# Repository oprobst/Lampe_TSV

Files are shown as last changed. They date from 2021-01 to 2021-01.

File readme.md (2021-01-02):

# TSV LED Sign

While cleaning up our workshop in our [TSV Malsch divers club](https://tsv-malsch.de), we found an old sign. It was equiped with E27 bulbs and some stroboscope flashes.
We decided activate it again and update it with RGB LED stripes. 
Since there were still some parts left in my electronic magazine cabinet, i decided to implement an LED controller at a reasonable price.

We extended the sign by a separate RGB LED Stripe array for the diver, and stripes for letters 'T', 'S', 'V'.
The circuit includes a button for selecting mode and some optional, internal status LEDs.

A button triggers an interrupt for an options menu. With this, the user can distinguish between 4 different modes.

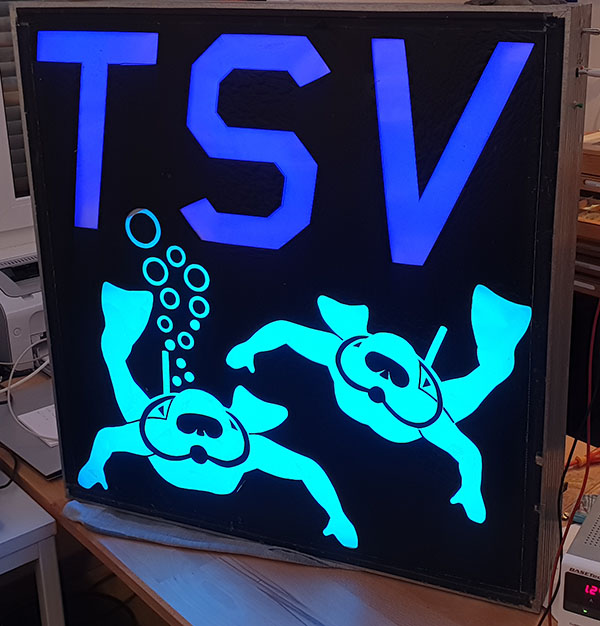
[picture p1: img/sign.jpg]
photo of the sign with led


The code could be more elegant, but it works. :)

## Modes

To change the mode, push the button on the left to switch through the differen options (visualized by a highlighted letter on the sign). 

First default mode is for the sign placed on the wall in the clubs workshop. Blue text and a slightly changing diver from green to blue and back.
Second and third changes the divers color constantly and also switching the letters color. Difference is the speed: While mode 2 is very slow (eg. for using it when selling things on a festival), mode 3 is fast and can be used on parties. Mode 4 is the disco mode, the whole sign flashes fast.

## Implementation

The controller is an Atmel ATMega 328P. It controls the major RGB light by 3 PWM pins. These 3 pins are connected to N-Channel mosfets (IRLZ 34N in this case). So it's possible to switch up to 68W per Channel. Unfortunatelly, the layout is not optimal, there is no place for heat sinks and the mosfest are close together. Very likely, this maximum is far out. But since the sign is currenly only using less than 4W per channel, this is not a problem..

To save costs, all other channels running a NPN transistor (BC550). This limits the maximum current to 100mA (= 1.2W on 12V).

## Wiring

Numbered from left to right when looking at the circuit from the top, black terminal bottom right. The black terminal is for connecting to 12V. The connector closest to the corner is GND.

Green Terminal (3.5mm)
| Pin | Purpose |
| ---: | --- |
|  1 | +12V out |
|  2 | High current RED channel |
|  3 | High current GREEN channel |
|  4 | High current BLUE channel |
|  5 | +12V out |
|  6 | Low current RED channel 1 |
|  7 | Low current GREEN channel 1 |
|  8 | Low current BLUE channel 1 |
|  9 | +12V out |
| 10 | Low current RED channel 2 |
| 11 | Low current GREEN channel 2 |
| 12 | Low current BLUE channel 2 |
| 13 | +12V out |
| 14 | Low current RED channel 3 |
| 15 | Low current GREEN channel 3 |
| 16 | Low current BLUE channel 3 |
| 17 | Multi purpose output 5V with 220 Ohm resistor, eg. for LED |
| 18 | Multi purpose output 5V with 220 Ohm resistor, eg. for LED |
| 19 | Multi purpose output 5V with 220 Ohm resistor, eg. for LED (used for button in V1.0) |
| 20 | Multi purpose output 5V with 220 Ohm resistor, eg. for LED (not connected in V1.0) |
| 21 | Multi purpose output 5V with 220 Ohm resistor, eg. for LED (not connected in V1.0) |
| 22 | +5V out |
| 23 | GND |
| 24 | Input pin for button. Push-up active, switch against GND to trigger |

## Pin out

### Diver LED:
* PD6 red	
* PD5 green
* PD3 blue

### Letter T
* PD4 red
*	PB0 green
*	PD7 blue

### Letter S
* PD0 red
*	PD1 green
*	PD2 blue

### Letter V
* PC3 red
*	PC5 green
*	PC4 blue

Input button: V1.0: PC0 V1.1: PB6  (Since there was a defect on the board 1.0, I used PC0 instead)
Status LED: PC1, PC2 (additional PC0, PB1, PB2 not connected so far)

## Circuit
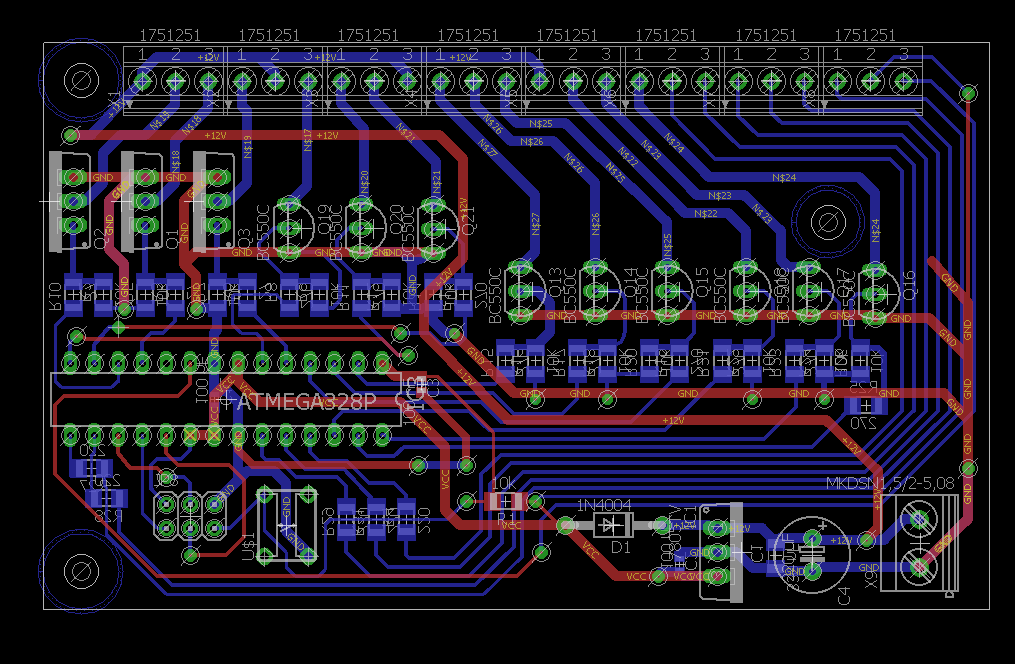
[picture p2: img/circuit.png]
Screenshot of circuit


## Schematics
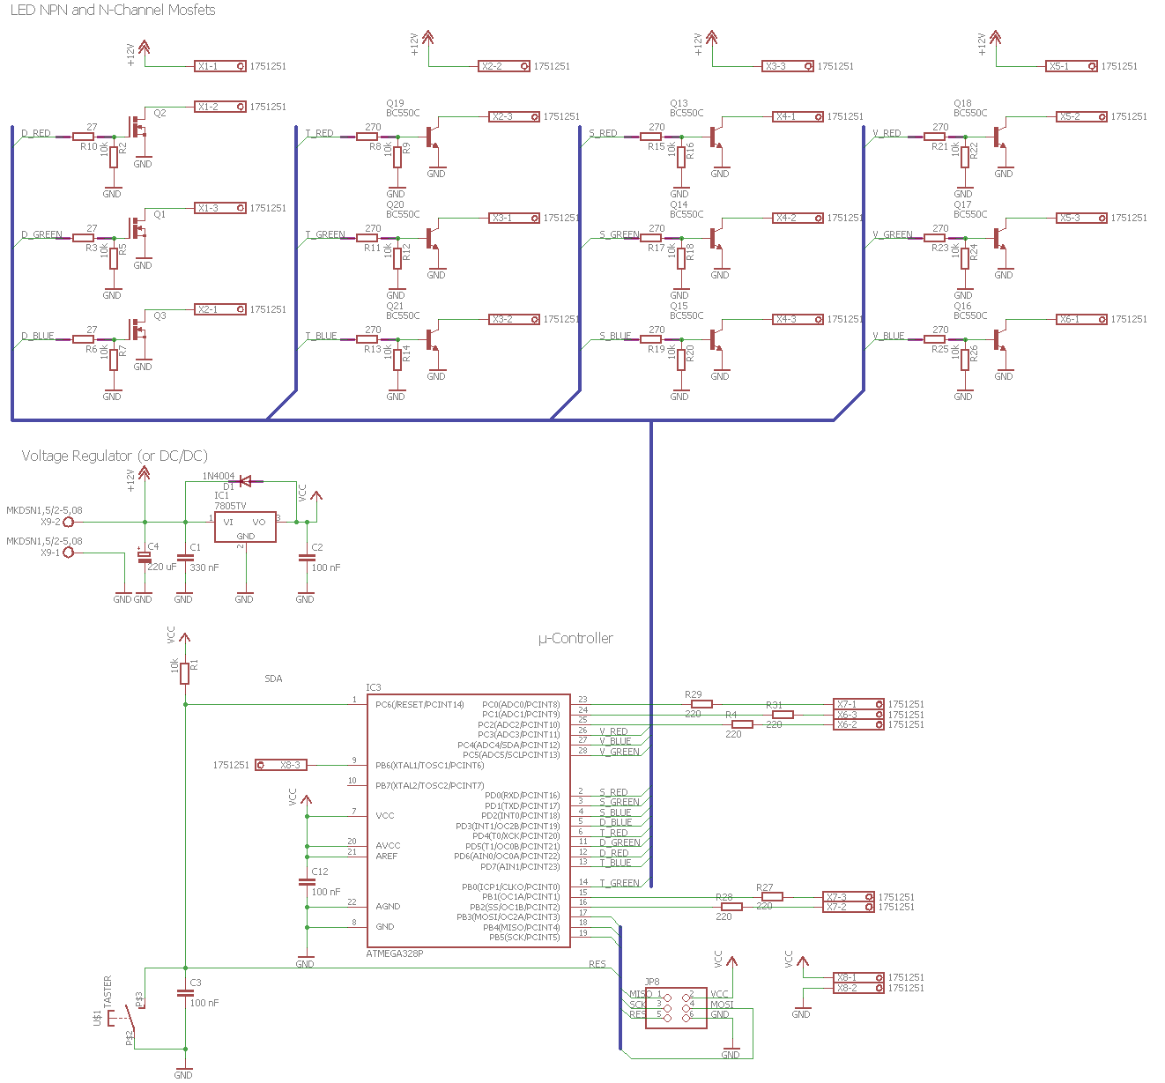
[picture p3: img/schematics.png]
Screenshot of schematics


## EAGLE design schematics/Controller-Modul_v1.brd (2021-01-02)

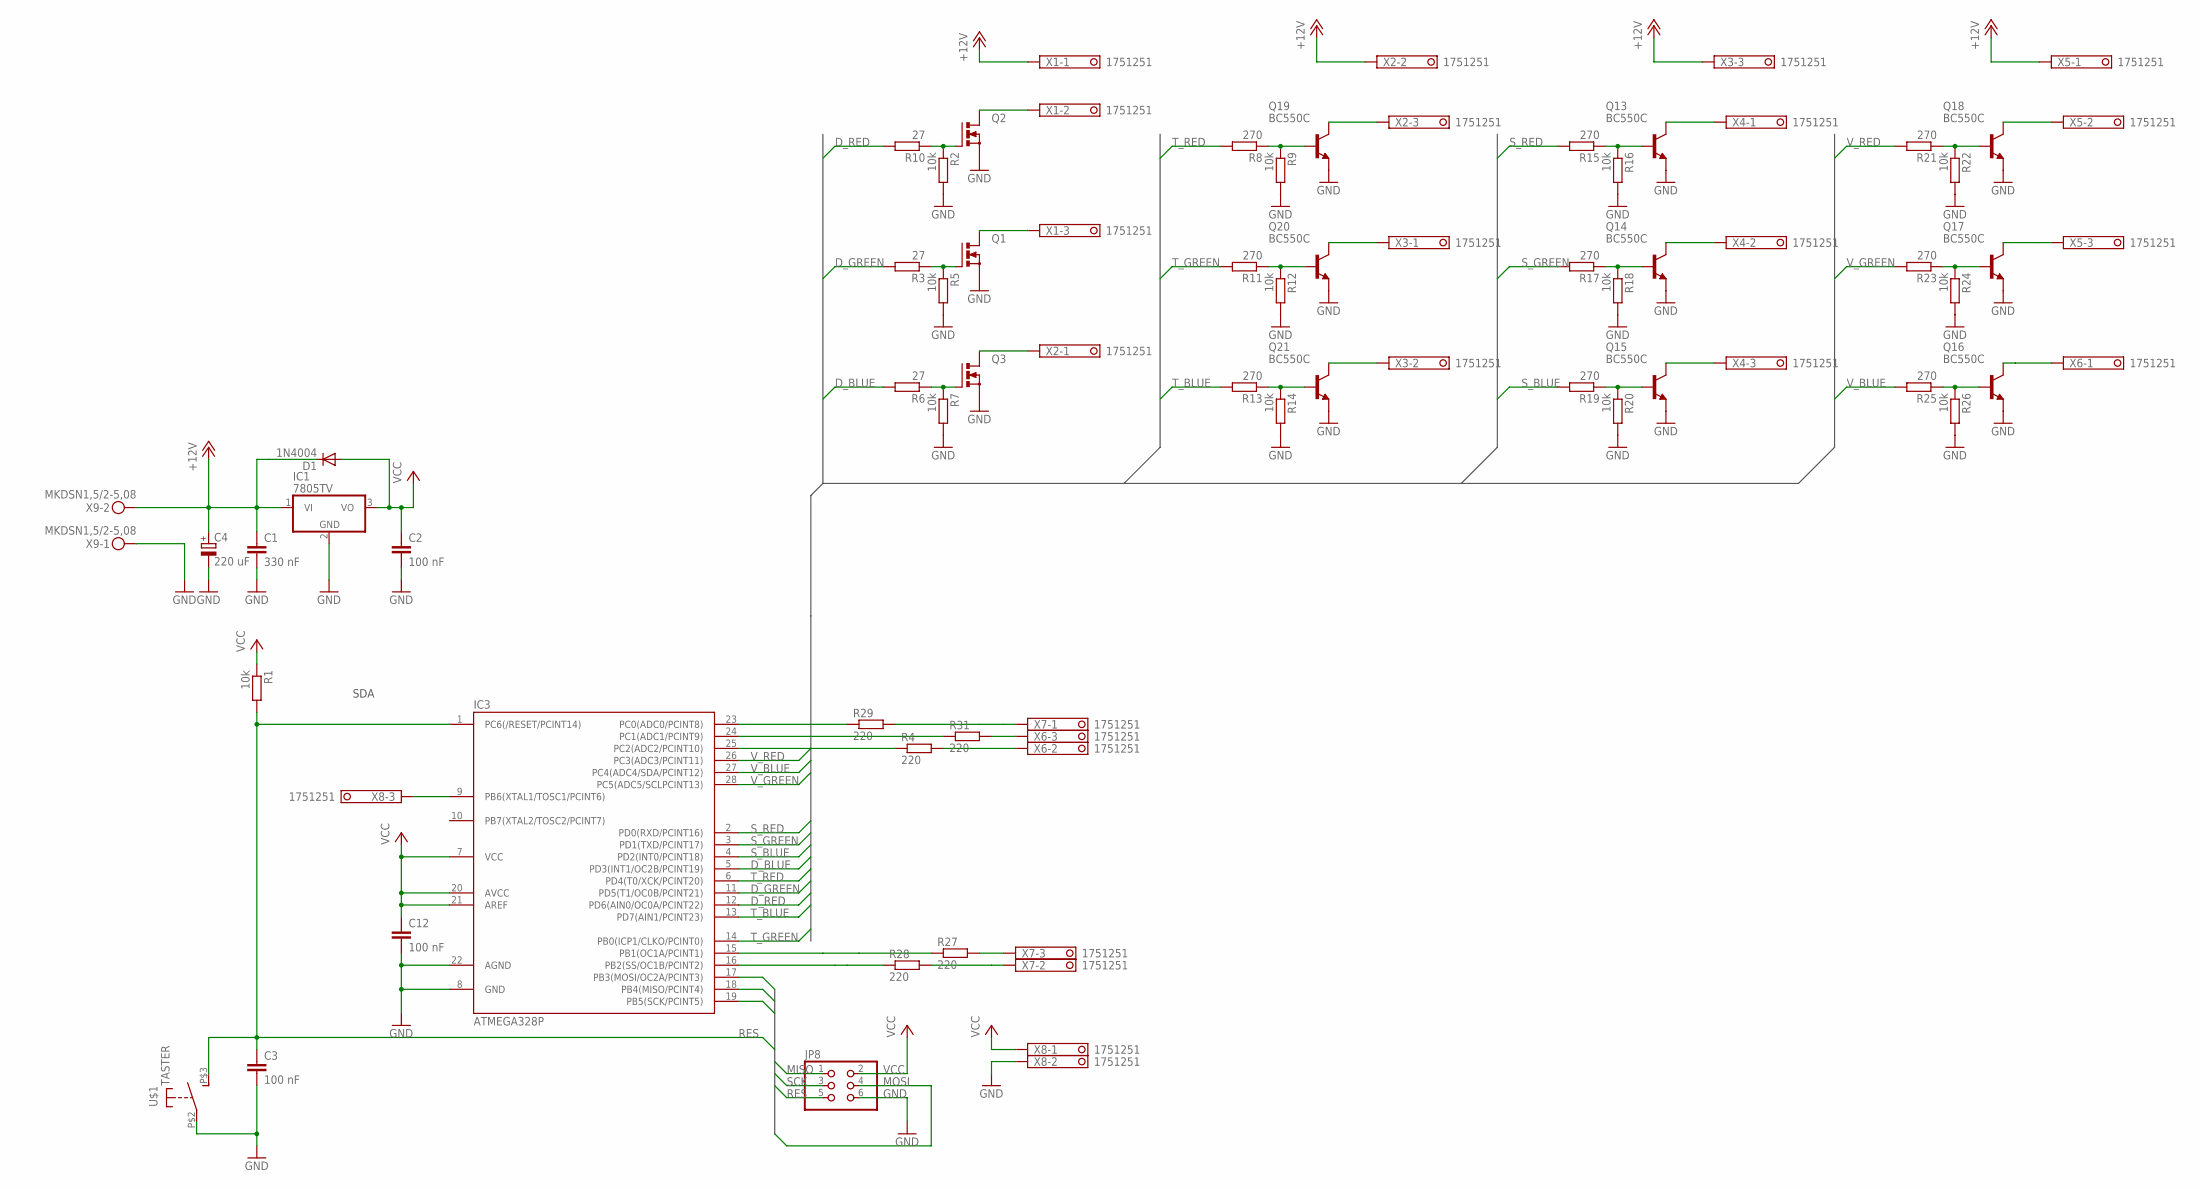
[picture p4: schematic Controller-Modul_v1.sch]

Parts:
C1: 330 nF; C1206
C2, C3, C12: 100 nF; C0603
C4: 220 uF; E3,5-8
D1: 1N4004; DO41-10
IC1: 7805TV; TO220V
IC3: ATMEGA328P; DIL28-3
JP8: PINHD-2X3; 2X03
Q1, Q2, Q3: PMOSFET_NTO220BV; TO220BV
Q13, Q14, Q15, Q16, Q17, Q18, Q19, Q20, Q21: BC550C; TO92-EBC
R1, R2, R5, R7, R9, R12, R14, R16, R18, R20, R22, R24, R26: 10k; R1206
R3, R6, R10: 27; R1206
R4, R27, R28, R29, R31: 220; R1206
R8, R11, R13, R15, R17, R19, R21, R23, R25: 270; R1206
U$1: TASTER; NAMAE-JTP-1130
X1, X2, X3, X4, X5, X6, X7, X8: 1751251
X9: MKDSN1,5/2-5,08

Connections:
+12V: C1.1, C4.+, D1.C, IC1.1 (VI), X1.1, X2.2, X3.3, X5.1, X9.2
D_BLUE: IC3.5 (PD3(INT1/OC2B/PCINT19)), R6.2
D_GREEN: IC3.11 (PD5(T1/OC0B/PCINT21)), R3.2
D_RED: IC3.12 (PD6(AIN0/OC0A/PCINT22)), R10.2
GND: C1.2, C2.2, C3.2, C4.-, C12.2, IC1.2 (GND), IC3.8 (GND), IC3.22 (AGND), JP8.6, Q1.S, Q2.S, Q3.S, Q13.E, Q14.E, Q15.E, Q16.E, Q17.E, Q18.E, Q19.E, Q20.E, Q21.E, R2.2, R5.2, R7.2, R9.2, R12.2, R14.2, R16.2, R18.2, R20.2, R22.2, R24.2, R26.2, U$1.P$2, X8.2, X9.1
MISO: IC3.18 (PB4(MISO/PCINT4)), JP8.1
MOSI: IC3.17 (PB3(MOSI/OC2A/PCINT3)), JP8.4
unnamed: Q1.G, R3.1, R5.1
unnamed: Q3.G, R6.1, R7.1
unnamed: IC3.24 (PC1(ADC1/PCINT9)), R31.1
unnamed: Q19.B, R8.1, R9.1
unnamed: Q20.B, R11.1, R12.1
unnamed: Q2.G, R2.1, R10.1
unnamed: Q21.B, R13.1, R14.1
unnamed: Q13.B, R15.1, R16.1
unnamed: Q14.B, R17.1, R18.1
unnamed: Q15.B, R19.1, R20.1
unnamed: Q18.B, R21.1, R22.1
unnamed: Q17.B, R23.1, R24.1
unnamed: Q16.B, R25.1, R26.1
unnamed: Q2.D, X1.2
unnamed: Q19.C, X2.3
unnamed: Q1.D, X1.3
unnamed: Q3.D, X2.1
unnamed: Q20.C, X3.1
unnamed: Q21.C, X3.2
unnamed: Q18.C, X5.2
unnamed: Q17.C, X5.3
unnamed: Q16.C, X6.1
unnamed: Q15.C, X4.3
unnamed: Q14.C, X4.2
unnamed: Q13.C, X4.1
unnamed: IC3.25 (PC2(ADC2/PCINT10)), R4.1
unnamed: IC3.23 (PC0(ADC0/PCINT8)), R29.1
unnamed: IC3.15 (PB1(OC1A/PCINT1)), R27.1
unnamed: IC3.16 (PB2(SS/OC1B/PCINT2)), R28.1
unnamed: R31.2, X6.3
unnamed: R4.2, X6.2
unnamed: R27.2, X7.3
unnamed: R29.2, X7.1
unnamed: R28.2, X7.2
unnamed: IC3.9 (PB6(XTAL1/TOSC1/PCINT6)), X8.3
RES: C3.1, IC3.1 (PC6(/RESET/PCINT14)), JP8.5, R1.2, U$1.P$3 (S)
SCK: IC3.19 (PB5(SCK/PCINT5)), JP8.3
S_BLUE: IC3.4 (PD2(INT0/PCINT18)), R19.2
S_GREEN: IC3.3 (PD1(TXD/PCINT17)), R17.2
S_RED: IC3.2 (PD0(RXD/PCINT16)), R15.2
T_BLUE: IC3.13 (PD7(AIN1/PCINT23)), R13.2
T_GREEN: IC3.14 (PB0(ICP1/CLKO/PCINT0)), R11.2
T_RED: IC3.6 (PD4(T0/XCK/PCINT20)), R8.2
VCC: C2.1, C12.1, D1.A, IC1.3 (VO), IC3.7 (VCC), IC3.20 (AVCC), IC3.21 (AREF), JP8.2, R1.1, X8.1
V_BLUE: IC3.27 (PC4(ADC4/SDA/PCINT12)), R25.2
V_GREEN: IC3.28 (PC5(ADC5/SCLPCINT13)), R23.2
V_RED: IC3.26 (PC3(ADC3/PCINT11)), R21.2

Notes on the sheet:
SDA

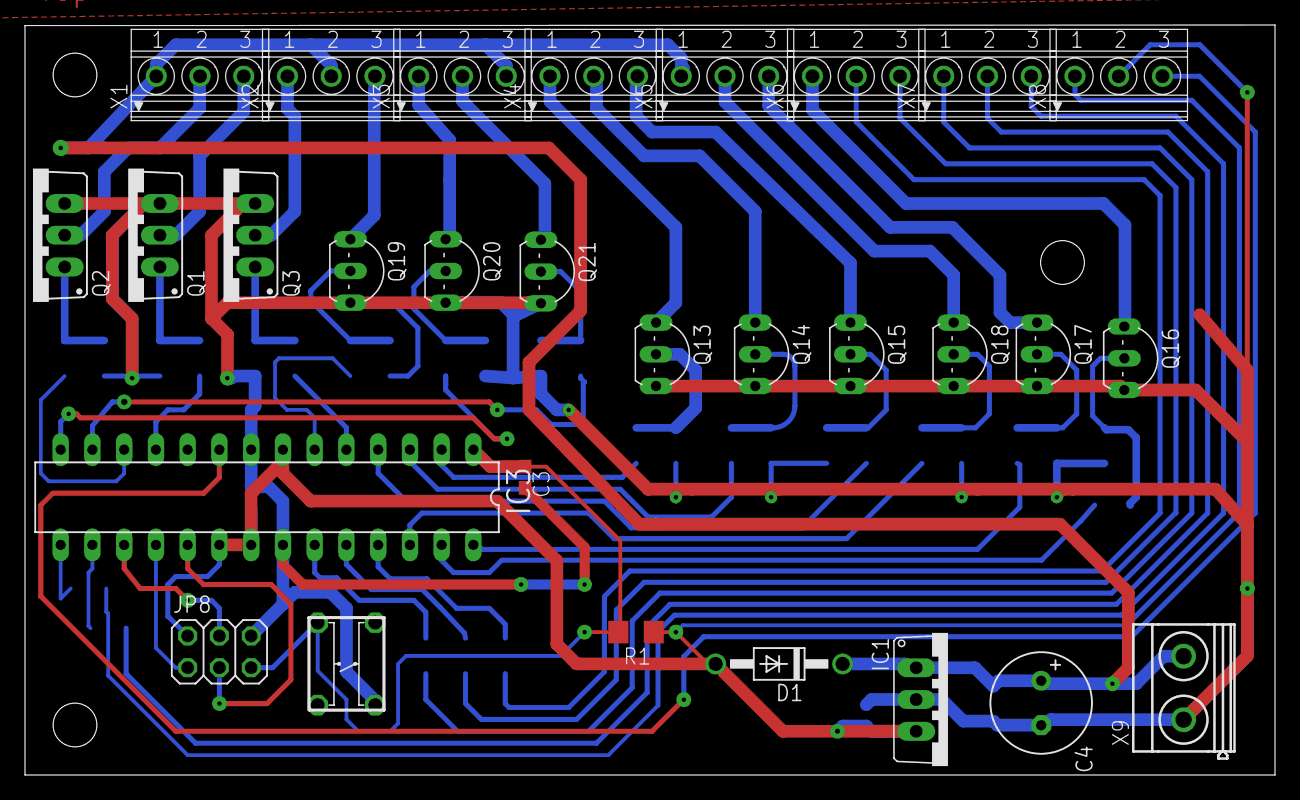
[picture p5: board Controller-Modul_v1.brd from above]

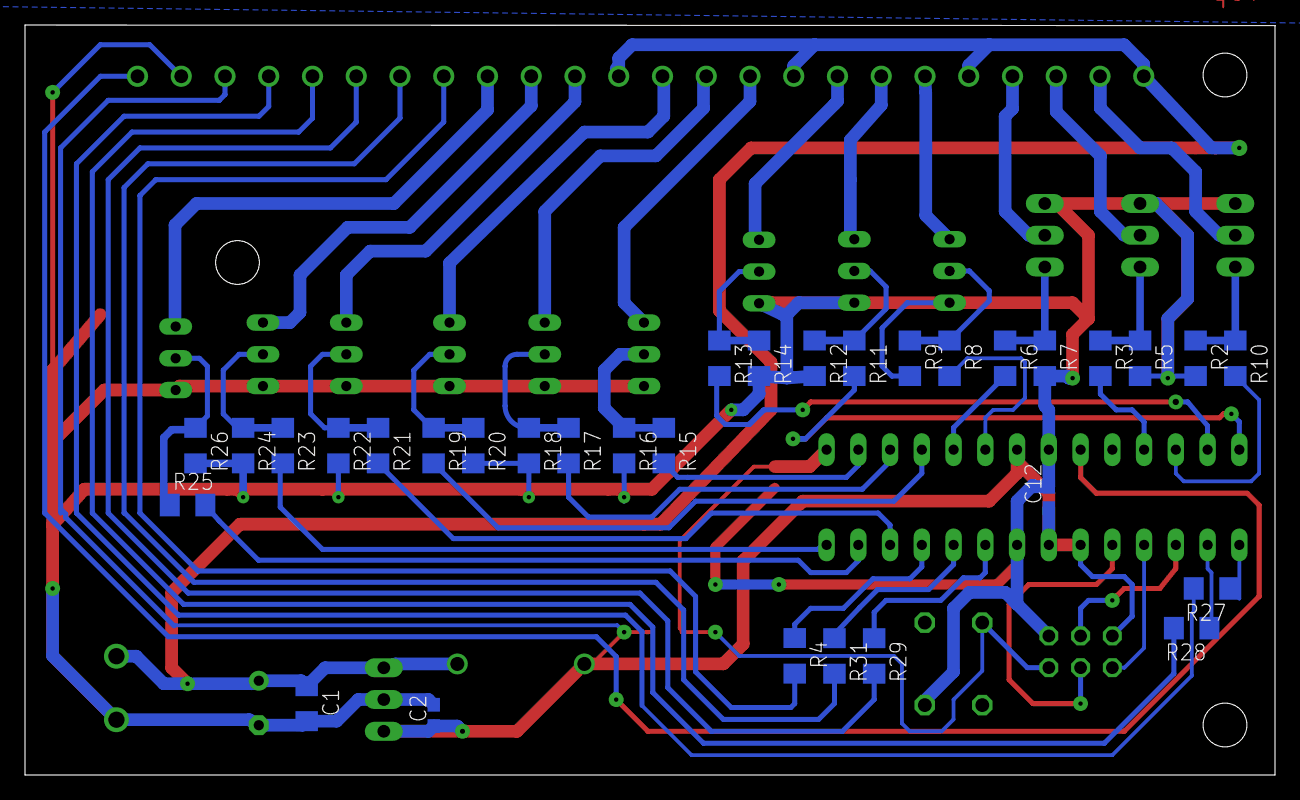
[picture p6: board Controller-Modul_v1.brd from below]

Board: 2 copper layers, 100.0 x 60.0 mm, 61 parts (32 on the bottom side), 54 nets.

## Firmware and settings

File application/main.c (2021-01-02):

#define F_CPU 8000000

#include <avr/io.h>
#include <util/delay.h>
#include <stdint.h>
#include <stdlib.h>
#include <avr/interrupt.h>

#define OFF 0
#define RED 1
#define GREEN 2
#define BLUE 3
#define PURPLE 4
#define CYAN 5
#define YELLOW 6
#define WHITE 7

#define FALSE 0
#define TRUE 1

#define SKIP_INTRO 0

static  uint8_t optionSelected = 1;
static volatile uint8_t gotoMenu = FALSE;

/* 
TSV LED Sign

Contains RGB LED Stripe array for diver, and stripes for  for letters 'T', 'S', 'V'.
Includes a button for selecting mode and some optional status LEDs.

Circuit Layout

Diver LED:		Letter T	Letter S	Letter V
PD6 red			PD4 red		PD0 red		PC3 red
PD5 green		PD7 blue	PD1 green	PC5 green
PD3 blue		PB0 green	PD2 blue	PC4 blue

Input button: PB6
Status LED: PC1, PC2 (additional PC0, PB1, PB2 not connected so far)

*/


void setup() {
	//init output pins
	DDRB |= (1<<PB0) | (1<<PB1) | (1<<PB2);
	DDRC |= (1<<PC1) | (1<<PC2) | (1<<PC3) | (1<<PC4) | (1<<PC5);
	DDRD |= (1<<PD0) | (1<<PD1) | (1<<PD2) | (1<<PD3) | (1<<PD4) | (1<<PD5) | (1<<PD6) | (1<<PD7);
	
	// set pin for button
	PORTC = (1<<PC0);
	DDRC &= ~(1 << PINC0);
	
	//init PWMs:
	//OC2B (PD3) - Diver blue
	//OC0B (PD5) - Diver green
	//OC0A (PD6) - Diver red
	 
	TCCR2A |= (1 << COM2B1);
	TCCR2A |= (1 << WGM21) | (1 << WGM20);
	TCCR0B  |= (1 << WGM01) | (1 << WGM00);
	TCCR0A |= (1<<COM0B1);
	TCCR0A |= (1 << COM0A1);
	TCCR0A |= (1 << WGM01) | (1 << WGM00);
	TCCR0B |= (1 << CS01);
	TCCR2B |= (1 << CS01);
	
	//pin change interrupt for PCINT 8 (=PC0 --> Button)
	PCICR |= (1 << PCIE1);
	PCMSK1 |= (1 << PCINT8);
	
	sei();
	
}

 
/*
 * Convenience method so set diver color.
 */ 
void colorDiver (uint8_t red, uint8_t green, uint8_t blue){
	OCR0A = red;
	OCR0B = green;
	OCR2B = blue;
}

/* 
 *Convenience method for letter. Use defined colors, like colorT(BLUE); 
 */
void colorT (uint8_t color){
	switch (color){
		case OFF:
			PORTB &= ~(1 << PB0);
			PORTD &= ~(1 << PD7);
			PORTD &= ~(1 << PD4);
			break;
		case BLUE:
			PORTB &= ~(1 << PB0);
			PORTD |=  (1 << PD7);
			PORTD &= ~(1 << PD4);
			break;
		case GREEN:
			PORTB |=  (1 << PB0);
			PORTD &= ~(1 << PD7);
			PORTD &= ~(1 << PD4);
			break;
		case RED:
			PORTB &= ~(1 << PB0);
			PORTD &= ~(1 << PD7);
			PORTD |=  (1 << PD4);
			break;
		case PURPLE:
			PORTB &= ~(1 << PB0);
			PORTD |=  (1 << PD7);
			PORTD |=  (1 << PD4);
			break;
		case YELLOW:
			PORTB |=  (1 << PB0);
			PORTD &= ~(1 << PD7);
			PORTD |=  (1 << PD4);
			break;
		case CYAN:
			PORTB |=  (1 << PB0);
			PORTD |=  (1 << PD7);
			PORTD &= ~ (1 << PD4);
			break;
		default: 
			PORTB |=  (1 << PB0);
			PORTD |=  (1 << PD7);
			PORTD |=  (1 << PD4);
			break;
	}
}

/* 
 *Convenience method for letter. Use defined colors, like colorS(BLUE); 
 */
void colorS (uint8_t color){
	switch (color){
		case OFF:
			PORTD &= ~(1 << PD0);
			PORTD &= ~(1 << PD1);
			PORTD &= ~(1 << PD2);
			break;
		case RED:
			PORTD |=  (1 << PD0);
			PORTD &= ~(1 << PD1);
			PORTD &= ~(1 << PD2);
			break;
		case GREEN:
			PORTD &= ~(1 << PD0);
			PORTD |=  (1 << PD1);
			PORTD &= ~(1 << PD2);
			break;
		case BLUE:
			PORTD &= ~(1 << PD0);
			PORTD &= ~(1 << PD1);
			PORTD |=  (1 << PD2);
			break;
		case PURPLE:
			PORTD |=  (1 << PD0);
			PORTD &= ~(1 << PD1);
			PORTD |=  (1 << PD2);
			break;
		case YELLOW:
			PORTD |=  (1 << PD0);
			PORTD |=  (1 << PD1);
			PORTD &= ~(1 << PD2);
			break;
		case CYAN:
			PORTD &= ~(1 << PD0);
			PORTD |=  (1 << PD1);
			PORTD |=  (1 << PD2);
			break;
		default: 
			PORTD |=  (1 << PD0);
			PORTD |=  (1 << PD1);
			PORTD |=  (1 << PD2);
			break;
	}
}


/* 
 *Convenience method for letter. Use defined colors, like colorV(BLUE); 
 */
void colorV (uint8_t color){
	switch (color){
		case OFF:
			PORTC &= ~(1 << PC4);
			PORTC &= ~(1 << PC5);
			PORTC &= ~(1 << PC3);
			break;
		case BLUE:
			 PORTC |=  (1 << PC4);
			 PORTC &= ~(1 << PC5);
			 PORTC &= ~(1 << PC3);
			 break;
		case GREEN:
			PORTC &= ~(1 << PC4);
			PORTC |=  (1 << PC5);
			PORTC &= ~(1 << PC3);
			break;
		case RED:
			PORTC &= ~(1 << PC4);
			PORTC &= ~(1 << PC5);
			PORTC |=  (1 << PC3);
			break;
		case PURPLE:
			PORTC |=  (1 << PC4);
			PORTC &= ~(1 << PC5);
			PORTC |=  (1 << PC3);
			break;
		case CYAN:
			PORTC |=  (1 << PC4);
			PORTC |=  (1 << PC5);
			PORTC &= ~(1 << PC3);
			break;
		case YELLOW:
			PORTC &= ~(1 << PC4);
			PORTC |=  (1 << PC5);
			PORTC |=  (1 << PC3);
			break;
		default: 
			PORTC |=  (1 << PC4);
			PORTC |=  (1 << PC5);
			PORTC |=  (1 << PC3);
			break;
	}
}

/*
 * Color for all letters
 */
void colorTSV (uint8_t t, uint8_t s, uint8_t v){
	colorT(t);
	colorS(s);
	colorV(v);
}
/*
 * Fancy start up animation
 */
void initSequence(){

    if (SKIP_INTRO) return;
	
	double speedLetter = 30; //ms
	double speedBlink = 350; //ms
	double fastBlink = 150; //ms


    uint8_t dRed = 0;
	uint8_t dGreen = 0;
	uint8_t dBlue = 0;

	colorDiver (0, 222, 1);
	colorTSV(CYAN, OFF, OFF);
	
	for (uint8_t i = 0; i < 20 ; i++){
	  dGreen += 1;
	  dRed += 1;
	  colorDiver (dRed, dGreen, dBlue);
	  _delay_ms(speedLetter);
	}		
	colorTSV(OFF, CYAN, OFF);
	
	for (uint8_t i = 0; i < 20 ; i++){
		dGreen += 1;
		dRed += 1;
		colorDiver (dRed, dGreen, dBlue);
		_delay_ms(speedLetter);
		if (gotoMenu) return;
	}
		
	colorTSV(OFF, OFF, CYAN);
	
	for (uint8_t i = 0; i < 40 ; i++){
		dBlue += 1;
		dRed -= 1;
		colorDiver (dRed, dGreen, dBlue);
		_delay_ms(speedLetter);
		if (gotoMenu) return;
	}
 
	
	colorTSV(CYAN, OFF, CYAN);
	
	for (uint8_t i = 0; i < 20 ; i++){		
		dGreen -= 1;
		colorDiver (dRed, dGreen, dBlue);
		_delay_ms(speedLetter);
		if (gotoMenu) return;
	}
	
	colorTSV(OFF, CYAN, CYAN);
	
	for (uint8_t i = 0; i < 20 ; i++){			
		dGreen -= 1;
		colorDiver (dRed, dGreen, dBlue);
		_delay_ms(speedLetter+speedLetter);
		if (gotoMenu) return;
	}
	
	
		
	colorTSV(CYAN, CYAN, CYAN);
	
	for (uint8_t i = 0; i < 20 ; i++){
		dRed += 1;
		colorDiver (dRed, dGreen, dBlue);
		_delay_ms(speedLetter);
		if (gotoMenu) return;
	}
		
	colorTSV(CYAN, CYAN, CYAN);
	_delay_ms(speedBlink);
	colorTSV(BLUE, BLUE, BLUE);
	_delay_ms(speedBlink);
	colorTSV(CYAN, CYAN, CYAN);
	_delay_ms(speedBlink);
	colorTSV(BLUE, BLUE, BLUE);	
	_delay_ms(speedBlink);
	for (uint8_t i = 0; i < 2; i++){
		colorTSV(RED, RED, RED);
		colorDiver (0, 255, 255);
		_delay_ms(fastBlink);		
		colorTSV(BLUE, BLUE, BLUE);
		_delay_ms(fastBlink);
		colorTSV(RED, RED, RED);
		colorDiver (dRed, dGreen, dBlue);
		_delay_ms(fastBlink);
		colorTSV(BLUE, BLUE, BLUE);
		
		_delay_ms(fastBlink);
	}
	
	for (uint8_t i = 0; i < 250 ; i++){			
		if (dRed >  5) dRed -= 1;
		if (dGreen < 250) dGreen += 1;
		if (dBlue < 250) dBlue += 1;
		colorDiver (dRed, dGreen, dBlue);
		_delay_ms(speedLetter+speedLetter);
		if (gotoMenu) return;
	}	
	
}

/*
 * this helper is used by mode2() and mode3()
void animationMode (double speed){
	uint8_t dRed = 0;
	uint8_t dGreen = 250;
	uint8_t dBlue = 250;			
	uint32_t wait = 0;
	while(!gotoMenu) {

		// fade green
		colorTSV(CYAN, GREEN, YELLOW);
		for (uint8_t i = 0; i < 250 ; i++){
			dBlue -= 1;
			colorDiver (dRed, dGreen, dBlue);
			while (wait++ < speed) _delay_ms(1);
			wait = 0;
			if (gotoMenu) return;
		}
		// fade yellow
		colorTSV(GREEN, YELLOW, PURPLE);
		for (uint8_t i = 0; i < 250 ; i++){
			dRed += 1;
			colorDiver (dRed, dGreen, dBlue);
			while (wait++ < speed) _delay_ms(1);
			wait = 0;
			if (gotoMenu) return;
		}		
		// fade purple
		colorTSV(YELLOW, PURPLE, BLUE);
		for (uint8_t i = 0; i < 250 ; i++){
			dBlue  += 1;
			dGreen -= 1;
			colorDiver (dRed, dGreen, dBlue);
			while (wait++ < speed) _delay_ms(1);
			wait = 0;
			if (gotoMenu) return;
		}
		// fade blue
		colorTSV(PURPLE, BLUE, CYAN);
		for (uint8_t i = 0; i < 250 ; i++){			
			dRed -= 1;
			colorDiver (dRed, dGreen, dBlue);
			while (wait++ < speed) _delay_ms(1);
			wait = 0;
			if (gotoMenu) return;
		}
		// fade cyan
		colorTSV(BLUE, CYAN, GREEN);
		for (uint8_t i = 0; i < 250 ; i++){
			dGreen  += 1;			
			colorDiver (dRed, dGreen, dBlue);
			while (wait++ < speed) _delay_ms(1);
			wait = 0;
			if (gotoMenu) return;
		}	
		
	}
}

/*
 * Default mode: from cyan to green and back within ca 1/2 hour. Text stays blue.
 */ 
void mode1 (){
	
	while(!gotoMenu) {
		double speed = 35;//ms
		uint8_t dRed = 5;
		uint8_t dGreen = 250;
		colorTSV(BLUE, BLUE, BLUE);
		 
		for (uint8_t i = 250; i > 0 ; i--){			
			colorDiver (dRed, dGreen, i);
			_delay_ms(speed);
			for (uint8_t j = 0; j < 100 ; j++){
				_delay_ms(speed);
				if (gotoMenu) return;
			}
		}
		for (uint8_t i = 0; i < 250 ; i++){		
			colorDiver (dRed, dGreen, i);
			for (uint8_t j = 0; j < 100 ; j++){
				_delay_ms(speed);
				if (gotoMenu) return;
			}
			
		}
	
	}		
}

/*
 * Mode 2: Colorful - changes colors slowly 
 */ 
void mode2 (){
	animationMode(100);
}

/*
 * Mode 3: Colorful - changes colors fast (eg. for party)
 */ 
void mode3 (){
	animationMode(10);
}


/*
 * Mode 4: Disco mode
 */ 
void mode4 (){
	
	uint8_t colorText = 1;
	while(optionSelected == 4) {
		if (++colorText > 8) colorText = 1;
		
		for (uint8_t i = 0; i < 5 ; i++){		
			colorDiver ( 255, 255,255);
			colorTSV (colorText, colorText, colorText);
			_delay_ms(30);
			colorDiver (0, 0, 0);
			colorTSV (0, 0, 0);
			_delay_ms(150);
			if (gotoMenu) return;
		}
	
	}		
}

/*
 * Change to user selected mode
 */
void changeMode (){
	gotoMenu = FALSE;
	switch (optionSelected){
		case 2:
		mode2();
		break;
		case 3:
		mode3();
		break;
		case 4:
		mode4();
		break;
		default:
		mode1();
		break;
	}
}
/*
 * Interrupt when button is pushed
 */
ISR(PCINT1_vect)
{
	gotoMenu = TRUE;
}

/*
 * Gives the user the opportunity to select the mode (workshop/party-slow/party-fast/disco)
 */
void selectMode (){
	cli();	
	gotoMenu = FALSE;
	optionSelected = 1;
	colorDiver(0,0,0);
	colorTSV(RED, OFF, OFF);
	_delay_ms(300);

	while (1){
		for (uint16_t i = 0; i < 300; i++ ){
			_delay_ms(10);
			if (!( PINC & (1<<PC0))){
				optionSelected = 2;
				colorTSV(OFF, RED, OFF);
				break;
			}
		}
		_delay_ms(300);
		if (optionSelected != 2) return;
    
	
		for (uint16_t i = 0; i< 300; i++ ){
			_delay_ms(10);
			if (!(  PINC & (1<<PC0))){
				optionSelected = 3;
				colorTSV(OFF, OFF, RED);
				break;
			}
		}
		_delay_ms(300);
		if (optionSelected != 3) return;
		
		for (uint16_t i = 0; i< 300; i++ ){
			_delay_ms(10);
			if (!(  PINC & (1<<PC0))){
				optionSelected = 4;
				colorTSV(OFF, OFF, OFF);
				colorDiver(250,0,0);
				break;
			}
		}
		_delay_ms(300);
		if (optionSelected != 4) return;
	
		for (uint16_t i = 0; i < 300; i++ ){
			_delay_ms(10);
			if (!( PINC & (1<<PC0))){
				optionSelected = 1;
				colorTSV(RED, OFF, OFF);
				colorDiver(0,0,0);
				break;
			}
		}
		_delay_ms(300);
		if (optionSelected !=1) return;
	}
}

int main(void) { 
	//initialize everything needed.
	setup();
	//show a startup sequence
	initSequence();	
	_delay_ms(1000);
	
	while (1){				
		// change the mode according to user selection (default on startup = 1)
		changeMode();		
		// changeMode will only be left when user push the button -> triggers an interrupt ending current mode.
		// give the user the option to select a new mode here:
		selectMode();
		// and enable interrupt for next selectMode() again.
		sei();
	}

}

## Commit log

2021-01-02 Initial checkin
    [Controller-Modul_v1.brd, Controller-Modul_v1.sch]
2021-01-02 Extended readme with info about button
